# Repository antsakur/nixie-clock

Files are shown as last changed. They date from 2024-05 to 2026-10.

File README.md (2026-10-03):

# Nixie clock

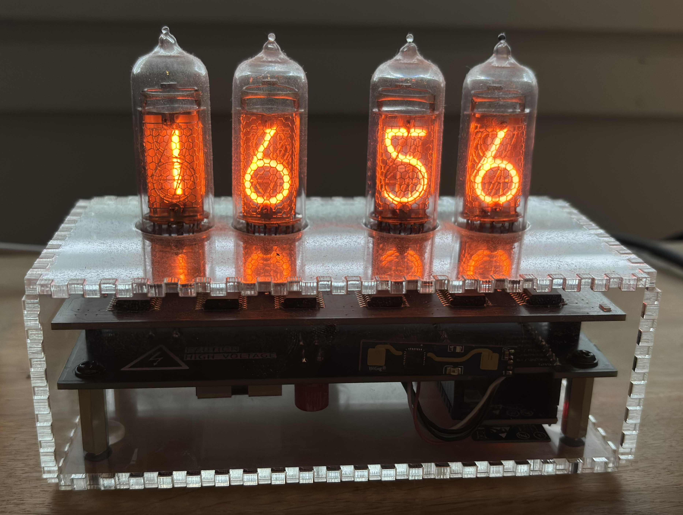
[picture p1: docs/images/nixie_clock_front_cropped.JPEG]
Nixie clock


ESP-IDF firmware for a four-tube HH:MM nixie clock on an ESP32-C6. The clock gets the time from SNTP over Wi-Fi, drives the tubes through shift registers, and serves a web page for setup and settings.

## Contents

- [What it does](#what-it-does)
- [How to use it](#how-to-use-it)
  - [First start](#first-start)
  - [Configuration](#configuration)
- [Functionality](#functionality)
  - [Display](#display)
    - [Clock](#clock)
    - [Cathode poisoning prevention routine](#cathode-poisoning-prevention-routine)
    - [Random digits](#random-digits)
  - [Brightness](#brightness)
  - [Presence](#presence)
  - [Time](#time)
  - [Network](#network)
- [How the hardware works](#how-the-hardware-works)
  - [Tubes](#tubes)
  - [Shift registers](#shift-registers)
  - [High-voltage supply](#high-voltage-supply)
  - [Presence sensor](#presence-sensor)
- [Build and flash](#build-and-flash)
- [Supported hardware](#supported-hardware)

## What it does

- Shows hours and minutes on four nixie tubes.
- Joins your saved Wi-Fi network and sets the clock from SNTP.
- Opens a setup network when it has no saved network, or when it cannot join.
- Can dim the tubes during night hours, and can turn the high-voltage supply off when nobody is nearby.
- Rolls the digits on a timer to reduce cathode poisoning.
- Crossfades digit changes when that effect is enabled.

Wi-Fi credentials are entered in the browser and stored on the clock.

## How to use it

### First start

1. Power the board from a 5 V supply that can provide 2 A, for example a USB phone charger. A 1 A supply may be insufficient. It opens a setup network named `NixieClock-XXXX`.
2. Join that network and open `http://nixie.local/`. If the name does not resolve, open `http://192.168.4.1/`.
3. Enter your SSID and password, then press **Join**. Tick **Hidden network** if the network is not advertised.
4. To access the configuration page, disconnect from the `NixieClock-XXXX` network, reconnect to your network, and open `http://nixie.local/` again.

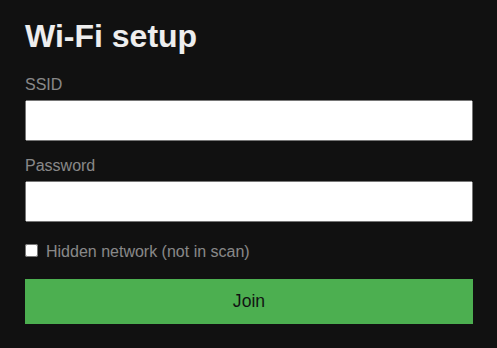
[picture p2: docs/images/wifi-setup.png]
Wi-Fi setup page


### Configuration

On your network, `http://nixie.local/` opens five menus. Each **Save settings** button stores that menu on the clock, and the values stay after a reboot.

| Menu | What you can change |
|---|---|
| Display | Fade, cathode-poisoning routine, and random digits |
| Brightness | Day and night levels, night hours, and the transition between them |
| Presence | Idle timeout that turns the tubes off |
| Time | Timezone and daylight saving |
| Network | Connection details, and forgetting the saved network |

**Forget current network** on the Network page clears the saved credentials and returns the clock to the setup network.

## Functionality

The pictures are the pages from a configured clock. The values in them are that clock's saved settings, not the defaults described here.

### Display

#### Clock

The clock normally shows the current time. When fade is enabled, a digit change crossfades from the old digits to the new ones. Fade duration is how long that crossfade takes. The default is 500 ms, and it can be set from 1 ms to 5000 ms. **Test fade** fades every digit back and forth using the fade duration that is currently set. **Show clock** returns to the time.

<figure class="clip">
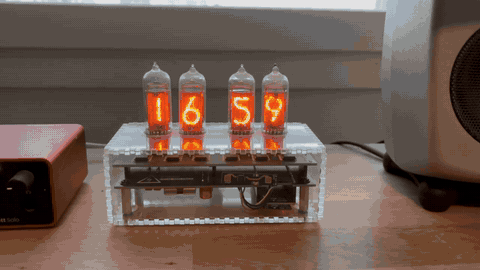
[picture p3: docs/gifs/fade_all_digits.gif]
Every digit fading

<figcaption><strong>All digits fading.</strong> Each tube crossfades to another digit and back, using the current fade duration.</figcaption>
</figure>

#### Cathode poisoning prevention routine

A nixie tube lights one cathode, the shaped digit, inside a gas-filled envelope. Metal slowly leaves the lit cathode and can settle on cathodes that stay dark. A clock repeats the same digits for long stretches, so unused digits grow dim, patchy, or fail to light. The routine walks every symbol on each tube so every cathode is lit regularly and that deposit does not build up.

You set the hold time for each digit, the starting offset, the run length, and whether it counts down. **Repeat every** is how many minutes pass between automatic runs. The default is 5 minutes. **Run cathode poisoning prevention routine** starts one run immediately.

<figure class="clip">
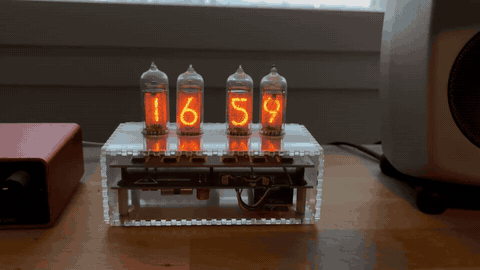
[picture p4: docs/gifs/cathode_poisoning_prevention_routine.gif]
Cathode poisoning prevention routine

<figcaption><strong>Cathode poisoning prevention.</strong> The tubes walk through every symbol so each cathode is lit.</figcaption>
</figure>

#### Random digits

Random digits shows a changing pattern instead of the time. You set the hold time and how long the pattern runs. **Run random** starts it.

<figure class="clip">
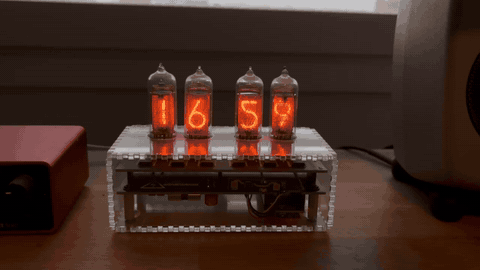
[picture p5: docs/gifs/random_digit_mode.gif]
Random digits

<figcaption><strong>Random digits.</strong> The tubes show a changing pattern instead of the time.</figcaption>
</figure>

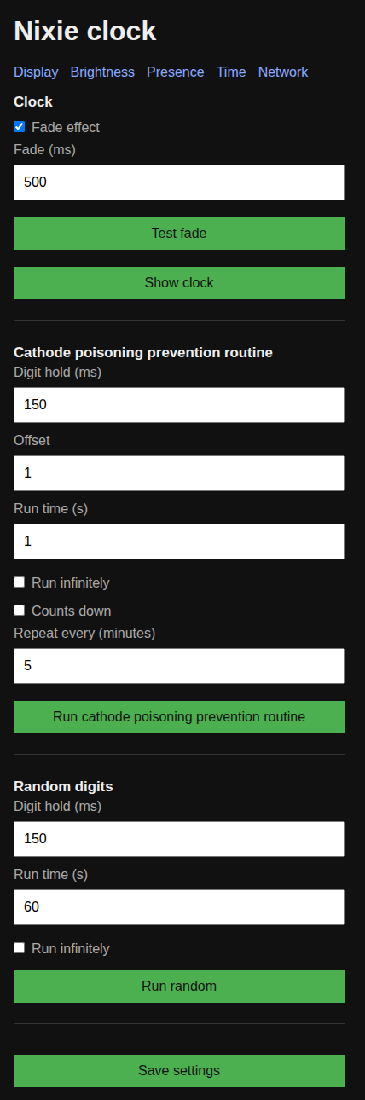
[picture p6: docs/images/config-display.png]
Display configuration page


### Brightness

Tube brightness is controlled with PWM. The brightness number is the PWM duty-cycle, from 0 to 100. The defaults are 80 during the day and 60 at night. Night mode is off by default. When it is on, it runs from a start hour until an end hour and may cross midnight. The default night hours are 23:00 to 07:00. **Transition** is how many seconds the brightness takes to move between those levels, from 1 to 60. The default is 10 seconds. **Test transition** runs one change between the day and night levels.

A brightness of 0 turns the high-voltage supply off.

<figure class="clip">
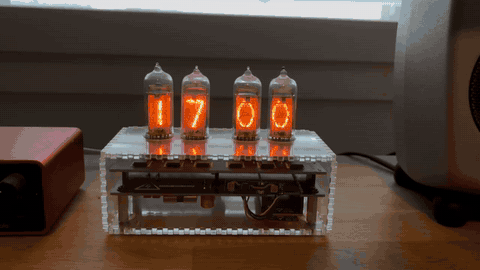
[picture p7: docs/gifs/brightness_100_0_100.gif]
Brightness moving from 100 to 0 and back to 100

<figcaption><strong>Brightness from full to off.</strong> The tubes dim from duty-cycle 100 to 0, then return to 100.</figcaption>
</figure>

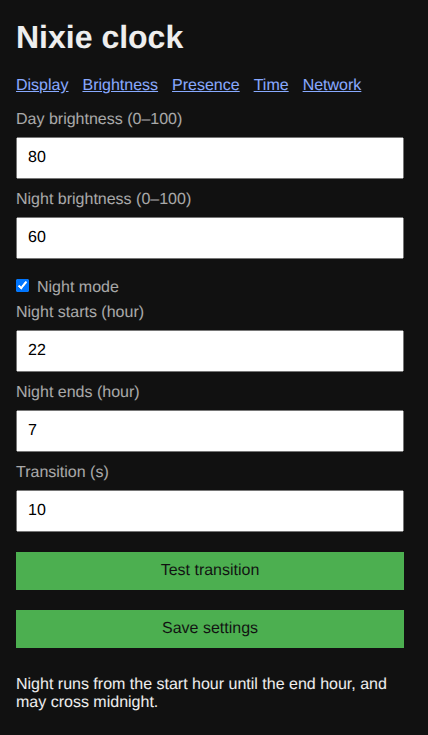
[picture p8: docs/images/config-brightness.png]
Brightness configuration page


### Presence

With the presence sensor enabled, the tubes turn off after the set number of minutes with nobody nearby. The default is 10 minutes. The allowed range is 1 to 240 minutes. Turning the sensor off leaves the tubes on, aside from a zero brightness setting.

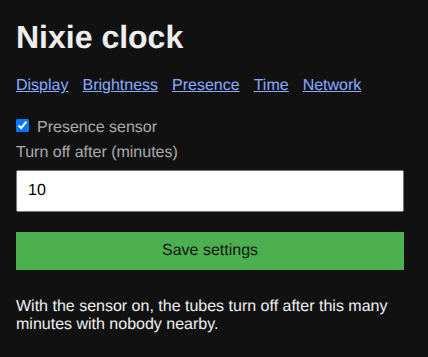
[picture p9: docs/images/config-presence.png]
Presence configuration page


### Time

Choose a timezone from the built-in list. Zones that observe daylight saving have a **Daylight saving** checkbox. The page shows the current clock time and the two SNTP servers compiled into the firmware. The defaults are `pool.ntp.org` and `time.google.com`.

The list covers UTC, the United Kingdom, Central and Eastern Europe, Finland, Moscow, India, China, Japan, Australia Eastern, and the four continental US zones.

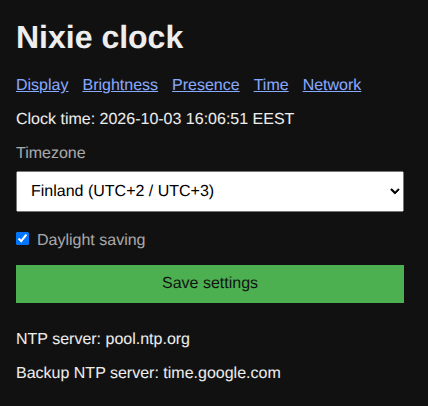
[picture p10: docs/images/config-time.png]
Time configuration page


### Network

The Network page shows the connected network, assigned IP address, firmware version, MAC address, and uptime. **Forget current network** erases the saved Wi-Fi credentials and starts the setup network again.

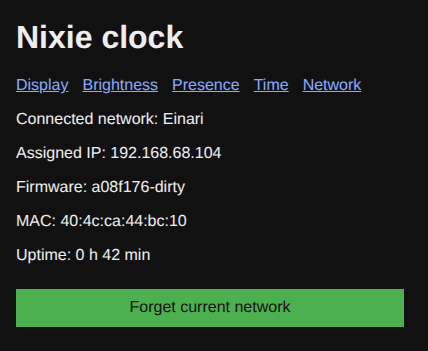
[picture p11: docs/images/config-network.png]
Network configuration page


## How the hardware works

The clock is two boards. The lower board makes 170 V from the 5 V input and carries the presence sensor. The upper board holds four IN-14 nixie tubes and the shift registers that select their digits. An ESP32-C6 development kit is the controller. It gets the time over Wi-Fi and drives the shift registers, the tube brightness, and the high-voltage enable pin.

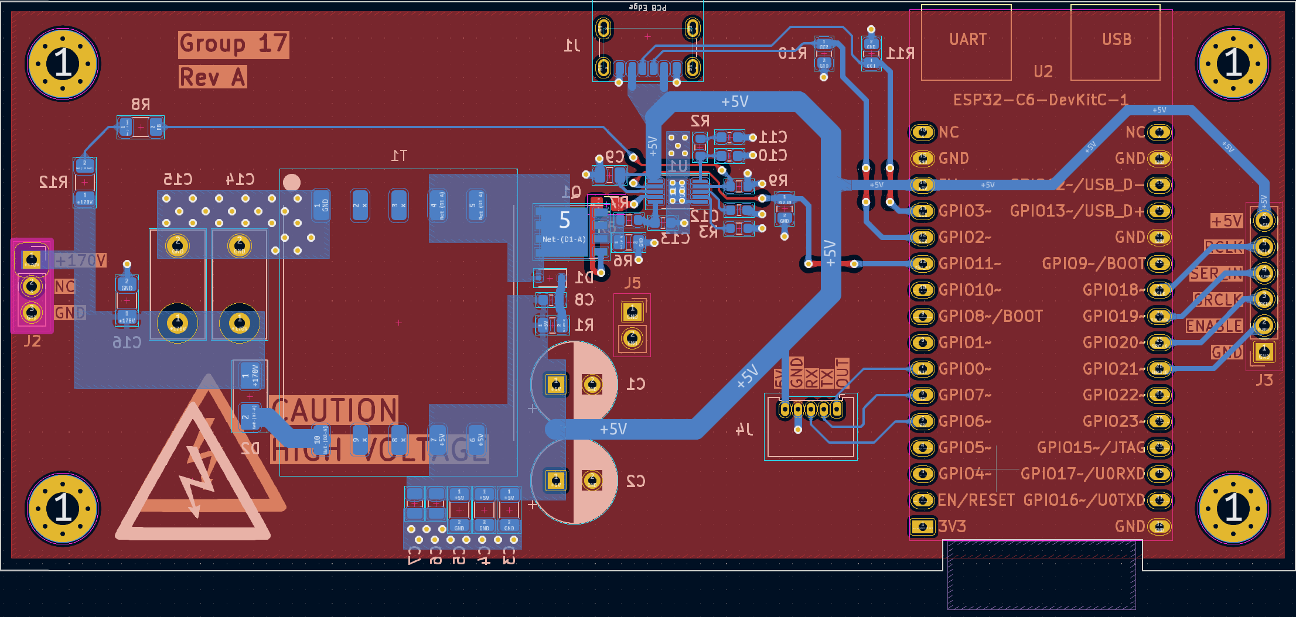
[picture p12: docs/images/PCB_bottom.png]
Lower board: 170 V supply, presence sensor, and controller


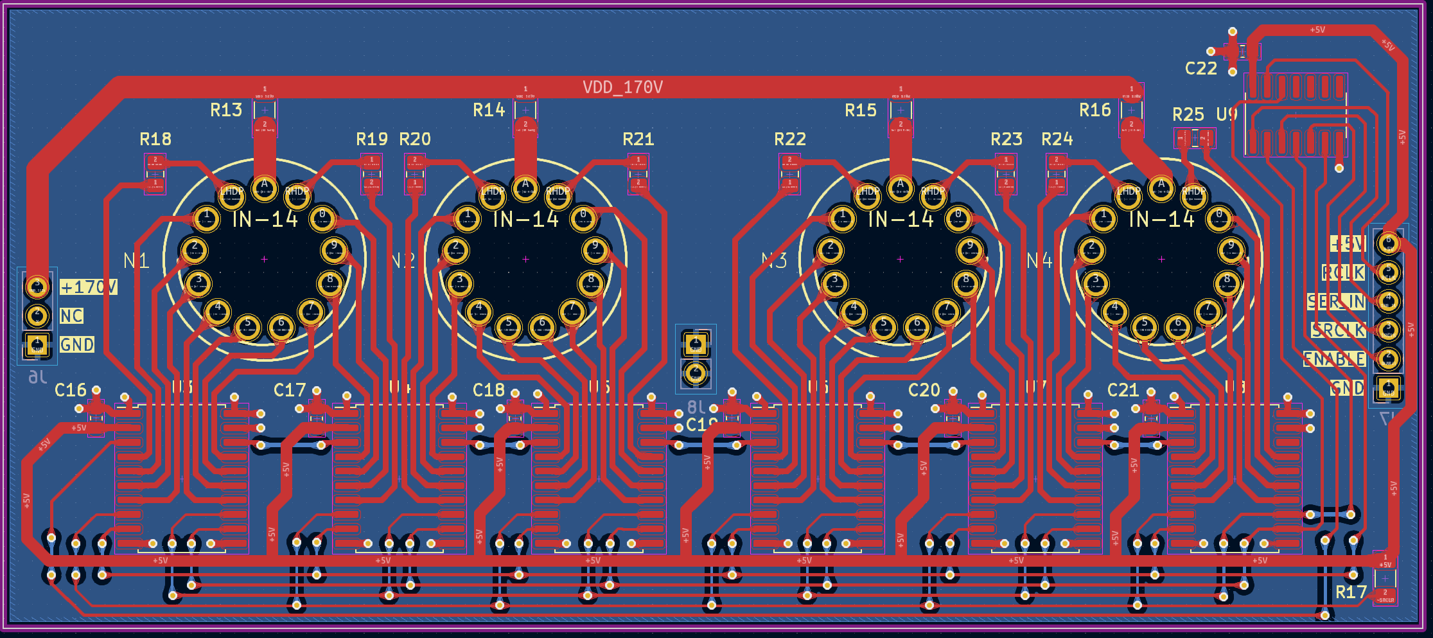
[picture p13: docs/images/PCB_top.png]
Upper board: four IN-14 tubes and shift registers


The high-voltage wiring can sit at 170 V while the clock is on. Do not touch that circuitry while it is powered.

### Tubes

Each IN-14 is a gas-filled tube with one common anode and a separate cathode for every symbol. About 170 V between the anode and a cathode ionizes the gas, and the glow takes the shape of that cathode. After the tube has struck, it keeps glowing at a lower voltage, about 145 V. The tube then looks like a short circuit, so each anode has a 13 kΩ resistor that holds the digit current to a few milliamps.

Each tube has cathodes for digits 0–9 and for a left and a right decimal point.

### Shift registers

Six TPIC6B595 shift registers are chained together. Each one has eight open-drain outputs that can pull a cathode to ground. An output that is on lights that cathode. An output that is off leaves it dark. The chain is 48 bits, sent least significant bit first:

| Bits | Tube |
|---|---|
| 47–36 | Hour tens |
| 35–24 | Hour ones |
| 23–12 | Minute tens |
| 11–0 | Minute ones |

Each group of 12 bits is one tube, in this order: left dot, digits 1 through 9, digit 0, right dot.

The controller sends serial data and a clock, then pulses the latch so all six registers update together. Output enable is a PWM signal. Its duty-cycle is the brightness number on the configuration page. The shift registers run from 5 V. Their outputs are clamped so they can sit at the tube voltage when a cathode is off.

### High-voltage supply

A flyback converter raises 5 V to 170 V for the tube anodes. An LT3757 controls the switch. The transformer is a Würth 750032051, with a 1:10 turns ratio so the switch duty-cycle stays in a practical range at 200 kHz. A BSC059N04LS6 MOSFET switches the primary. A VS-3EMH06 diode rectifies the secondary. An RCD snubber clamps the voltage spike on the MOSFET when it turns off. The converter is designed for about 20 mA at 170 V, which is enough for the four tubes. One GPIO enables the converter. Turning that pin off removes the anode voltage and the tubes go dark.

### Presence sensor

An HLK-LD2420 24 GHz radar module watches for a person nearby. It was chosen instead of a passive infrared sensor because it still sees someone who is sitting still. The clock only uses the module's presence output. A high level means someone is nearby, and a low level means the area is empty. When that output stays empty for the configured number of minutes, the firmware turns the high-voltage supply off.

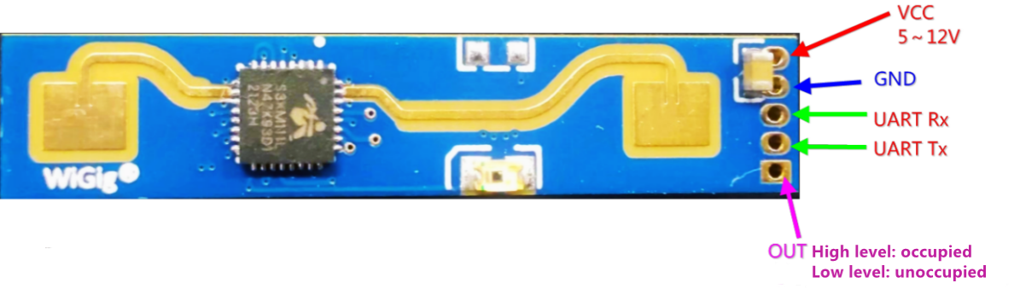
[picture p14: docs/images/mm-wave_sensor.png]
24 GHz presence sensor


## Build and flash

You need ESP-IDF 6.x. The target is `esp32c6`.

```bash
idf.py set-target esp32c6
idf.py menuconfig   # User Configuration: board and SNTP servers
idf.py build
idf.py -p /dev/ttyUSB0 flash monitor
```

In **User Configuration**:

- **Board** selects the DevKit pin map. The default is `ESP32_C6_WROOM_1`.
- **SNTP server** and **Backup SNTP server** are the only time servers the clock uses.
- **Initial connection retry count** is how many station disconnects to tolerate before giving up on credentials that have not yet received an IP, and before bringing the setup network back after a later disconnect. The default is 5.

Flash through the USB-UART bridge. The commands above use `/dev/ttyUSB0`.

## Supported hardware

| Board | Module | menuconfig |
|---|---|---|
| ESP32-C6-DevKitC-1 | ESP32-C6-WROOM-1 | `ESP32_C6_WROOM_1` (default) |
| ESP32-C6-DevKitM-1 | ESP32-C6-MINI-1 | `ESP32_C6_MINI_1` |

The firmware also expects:

- Four nixie tubes driven by shift registers (latch, data, and clock).
- A high-voltage supply with an enable pin.
- A PWM output-enable line for tube brightness.
- A presence sensor input.

Choosing the wrong board in menuconfig drives the high-voltage enable and the shift-register pins on the wrong GPIOs. The pin map for both kits is in [docs/esp32-c6-devkits.md](docs/esp32-c6-devkits.md).

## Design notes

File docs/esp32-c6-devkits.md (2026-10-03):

# ESP32-C6 DevKitM-1 vs DevKitC-1

Espressif entry-level boards for the same SoC family. They differ by **module**, **flash**, **footprint**, and **header pinout**, not by radio or CPU architecture.

Official user guides:

- [ESP32-C6-DevKitM-1](https://docs.espressif.com/projects/esp-dev-kits/en/latest/esp32c6/esp32-c6-devkitm-1/user_guide.html)
- [ESP32-C6-DevKitC-1](https://docs.espressif.com/projects/esp-dev-kits/en/latest/esp32c6/esp32-c6-devkitc-1/user_guide.html)

In this firmware, map kits in menuconfig **User Configuration → Board**:

| DevKit | Kconfig |
|---|---|
| ESP32-C6-DevKitC-1 | `ESP32_C6_WROOM_1` |
| ESP32-C6-DevKitM-1 | `ESP32_C6_MINI_1` |

Wrong board setting uses the wrong GPIOs (UART, HV PSU, shift registers). See `src/defines.h`.

---

## Differences

| | **ESP32-C6-DevKitM-1** | **ESP32-C6-DevKitC-1** |
|---|---|---|
| Module | ESP32-C6-**MINI-1**(U) | ESP32-C6-**WROOM-1**(U) |
| Typical flash (as kit docs) | **4 MB** in the chip package (`ESP32-C6FH4`) | **8 MB** SPI flash on the module |
| Module size | Smaller MINI (~13.2 × 16.6 mm class) | Larger WROOM (~18 × 25.5 mm class) |
| Antenna | PCB (`-1`) or U.FL (`-1U`) | Same: PCB vs U.FL |
| Header layout | Mini-oriented (e.g. **GPIO14** brought out; not the same J1 map as C) | Classic DevKitC (**GPIO10**, **GPIO11** on J1; extra NC pins) |
| Name | **M** = MINI module | **C** = WROOM / DevKitC-style |

The **U** SKUs change antenna only (connector vs PCB).

---

## Shared specifications

Both kits:

| Item | Spec |
|---|---|
| SoC | ESP32-C6, 32-bit RISC-V HP core (up to **160 MHz**) + LP core |
| Wi-Fi | 2.4 GHz **Wi-Fi 6** (802.11ax) |
| Bluetooth | **Bluetooth 5 (LE)** |
| 802.15.4 | Zigbee 3.0 / Thread 1.3 |
| USB | Two Type-C ports: native **USB Serial/JTAG** (USB 2.0 full speed, 12 Mbps) and **USB-UART bridge** (up to ~3 Mbps) |
| Power | USB and/or 5 V / 3.3 V headers; 5 V → 3.3 V LDO |
| Debug | BOOT, RST, RGB LED (typically **GPIO8**), current-measure jumper **J5** |
| I/O | Most GPIOs on headers (ADC, UART, I2C, SPI, USB D+/D− on GPIO13 / GPIO12) |

---

## Kit details

### ESP32-C6-DevKitM-1

- Module: ESP32-C6-MINI-1 or MINI-1U
- Flash: **4 MB** in-package on the kit Espressif documents (some MINI part numbers exist with more flash)
- Chip: **ESP32-C6FH4**
- Use when matching a small MINI production module

### ESP32-C6-DevKitC-1 (user guide v1.2)

- Module: ESP32-C6-WROOM-1 or WROOM-1U
- Flash: **8 MB** SPI
- Chip: ESP32-C6 with flash on the module
- Use when you want extra flash and the usual DevKitC header map

---

## Firmware pin map (this project)

| Signal | WROOM-1 / DevKitC-1 | MINI-1 / DevKitM-1 |
|---|---|---|
| Presence | GPIO0 | GPIO0 |
| USB-C CC1 / CC2 | GPIO2 / GPIO1 | — |
| UART RX / TX | GPIO6 / GPIO7 | GPIO4 / GPIO5 |
| HV PSU enable | GPIO11 | GPIO7 |
| Shift-reg latch | GPIO18 | GPIO15 |
| Shift-reg data | GPIO19 | GPIO18 |
| Shift-reg clock | GPIO20 | GPIO19 |
| Shift-reg output enable (PWM) | GPIO21 | GPIO20 |

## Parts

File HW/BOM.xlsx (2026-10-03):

Item # | Qty |  | Ref Des | Manufacturer | Manf part num | Description | Footprint | Type | Digikey price/pc (€) | Total
 |  | Comment
 |  | Capacitors |  |  |  |  |  |  | excluding VAT
 | 1 | 100pF | C10 | Yageo | CC0603JRNPO9BN101 | Multilayer Ceramic Capacitor, 100 pF, 50 V, ± 5%, C0G (NP0), 0603 [1608 Metric] | 0603 | SMT | 0.09 | 0.09
 | 1 | 10nf, 500V, X7R | C16 | Wurth Elektronik | 885342208009 | Cap Cer 10000PF 500V X7R 1206 | 1206 | SMT | 0.12 | 0.12
 | 1 | 10nf | C13 | Murata | GCM188R72A103KA37D | Multilayer Ceramic Capacitor, 0.01 uF, 100 V, ± 10%, X7R, 0603 [1608 Metric] | 0603 | SMT | 0.09 | 0.09
 | 2 | 22nf, 100V | C8,C11 | Murata | GCM188R72A223KA37J | Multilayer Ceramic Capacitor, 0.022 uF, 100 V, ± 10%, X7R, 0603 [1608 Metric] | 0603 | SMT | 0.1 | 0.20
 | 2 | 68nf, 400V | C14, C15 | Wurth Elektronik | 890283422001CS | Cap, 0.068Uf, 400V, Film, Radial Rohs Compliant: Yes |Wurth Elektronik 890283422001CS | WCAP-FTBE_L10.5xH11xP7.5 | THT | 0.44 | 0.88
 | 7 | 100nf, 16V | C12, C17-22 | Yageo | CC0603KRX7R7BB104 | Multilayer Ceramic Capacitor, 0.1 uF, 16 V, ± 10%, X7R, 0603 [1608 Metric] | 0603 | SMT | 0.039 | 0.27
 | 2 | 1uf, 25V, X7R | C6,C7 | Samsung | CL21B105KAFNNNE | Multilayer Ceramic Capacitor, 1 uF, 25 V, ± 10%, X7R, 0805 [2012 Metric] | 0805 | SMT | 0.09 | 0.18
 | 3 | 10uf, 25V, X7R | C3,C4,C5 | Samsung | CL31B106KAHNFNE | Multilayer Ceramic Capacitor, 10 uF, 25 V, ± 10%, X7R, 1206 [3216 Metric] | 1206 | SMT | 0.21 | 0.63
 | 1 | 47uF, 16V, X7R | C9 | Murata | GRM21BR71C475KE51L | Multilayer Ceramic Capacitor, 4.7 uF, 16 V, ± 10%, X7R, 0805 [2012 Metric] | 0805 | SMT | 0.14 | 0.14
 | 2 | 47uF, 25V | C1,C2 | Wurth Elektronik | 870025574002 | WCAP-PTG5 Aluminum Polymer Capacitors | WCAP-PTG5_D8xH8xP3.5 | THT | 0.68 | 1.36
 | 1 | 0 | R5 | Yageo | RC0805FR-070RL | Thick film chip resistor; smd; 0805; 0.00R; 0.125W; 1%; ; operating temperature: -55°C~125°C | 0805 | SMT | 0.09 | 0.09
 | 1 | 2 | R5 | Yageo | RC0805FR-072RL | SMD Chip Resistor, 2 Ohm, ± 1%, 125 mW, 0805 [2012 Metric], Thick Film, General Purpose | 0805 | SMT | 0.09 | 0.09
 | 1 | 33m, 3/4W | R6 | Thin Film Tech | D1WEL0805MR033F-T5 | Res 0.033 Ohm 1% 3/4W 0805 | 0805 | SMT | 0.42 | 0.42
 | 1 | 20 | R12 | Yageo | RC1206JR-0720RL | SMD Chip Resistor, 20 Ohm, ± 5%, 250 mW, 1206 [3216 Metric], Thick Film, General Purpose | 1206 | SMT | 0.09 | 0.09
 | 1 | 22 | R7 | Yageo | RC0603FR0722RL | SMD Chip Resistor, 22 Ohm, ± 1%, 100 mW, 0603 [1608 Metric], Thick Film, General Purpose | 0603 | SMT | 0.09 | 0.09
 | 1 | 4.7k, 0.4W | R1 | Vishay | RCS08054K70FKEA | Res Thick Film 0805 4.7K Ohm 1% 0.4W ±100ppm/°C Pad SMD Automotive Medical T/R | 0805 | SMT | 0.12 | 0.12
 | 2 | 5.1k, 1% | R10,R11 | Yageo | RC0805FR-075K1L | SMD Chip Resistor, 5.1 kOhm, ± 1%, 125 mW, 0805 [2012 Metric], Thick Film, General Purpose | 0805 | SMT | 0.09 | 0.18
 | 1 | 6.8k | R2 | Yageo | RC0603FR-076K8L | SMD Chip Resistor, 6.8 kOhm, ± 1%, 100 mW, 0603 [1608 Metric], Thick Film, General Purpose | 0603 | SMT | 0.09 | 0.09
 | 5 | 13k | R13-17 | KOA Speer | RK73B2BTTD133J | Res Thick Film 1206 13K Ohm 5% 0.25W(1/4W) ±200ppm/C Pad SMD Automotive T/R | 1206 | SMT | 0.03 | 0.15
 | 1 | 15k | R9 | Yageo | RC0603FR-0715KL | SMD Chip Resistor, 15 kOhm, ± 1%, 100 mW, 0603 [1608 Metric], Thick Film, General Purpose | 0603 | SMT | 0.09 | 0.09
 | 1 | 63.4k | R3 | Stackpole Electronics | RMCF0603FT63K4 | Res Thick Film 0603 63.4K Ohm 1% 1/10W ±100ppm/°C Molded SMD SMD Paper T/R | 0603 | SMT | 0.09 | 0.09
 | 8 | 100k | R18-R25 | Yageo | RC0805FR-07100KL |  | 0805 | SMT
 | 1 | 1.6M | R8 | Yageo | RC1206FR-071M6L | SMD Chip Resistor, 1.6 MOhm, ± 1%, 250 mW, 1206 [3216 Metric], Thick Film, General Purpose | 1206 | SMT | 0.09 | 0.09
 | 1 | 2A, 600V | D2 | Vishay | VS-3EMH06-M3/5AT | Diode Hyper Fast Recovery Rectifier 600V 3A 2-Pin DO-214AC Plastic T/R | SMA (DO-214AC) | SMT | 0.40 | 0.40
 | 1 | 0.25A, 100V | D1 | Diodes Inc. | 1N4148WSF-7 | Rectifier Diode Small Signal Switching 100V 0.25A 4ns 2-Pin SOD-323F T/R | SOD323F | SMT | 0.17 | 0.17
 | 1 | 40V | Q1 | Infineon | BSC059N04LS6 | OptiMO 6 40V power MOSFETs combining best-in-class RDS(on) with superior switching performance | TDSON-8 FL | SMT | 1.05 | 1.05
 | 1 | 10uH | T1 | Wurth Elektronik | 750032051 | Pulse Transformer, 1: 10, 10 H, 0.7 Ohm, 1 Kv | - | SMT | 4.68 | 4.68
 | 1 | LT3757A | U1 | Analog Devices | LT3757AEMSE#PBF | DC DC Cntrlr Single-OUT Flyback Controller 2.9V to 40V Input Automotive 10-Pin MSOP EP | 10-TFSOP, 10-MSOP (0.118", 3.00mm Width) Exposed Pad | SMT | 6.15 | 6.15
 | 6 | TPIC6B595 | U3-U8 | Texas Instruments | TPIC6B595DWR | 8 Bit Sipo Shift Register, SOIC-20; Shif; Msl: Msl 1 - Unlimited; Svhc: No Svhc (15-JAN-2019) | 20-SOIC | SMT | 1.39 | 8.34
 | 1 | SN74HCT04 | U9 | Texas Instruments | SN74HCT04DR | 6-ch, 4.5-V to 5.5-V inverters with TTL-compatible CMOS inputs 14-SOIC -40 to 85 | 14-SOIC | SMT | 0.33 | 0.33
 | 1 | USB4125 | J1 | GCT | USB4125-GF-A-0190 | 24 (6+18 Dummy) Position USB-C (USB TYPE-C) USB 2.0 Receptacle Connector | USB 6P | THT | 0.62 | 0.62
 | 1 | 5POS 1.25mm | J4 | Molex | 0530480510 | Conn Shrouded Header (4 Sides) HDR 5 POS 1.25mm Solder RA Side Entry Thru-Hole PicoBlade Tray | 1x05_P1.25mm | THT | 0.45 | 0.45
 | 1 | 5POS 1.25mm | - | Molex | 0510210500 | MOLEX 51021-0500 1.25mm Pitch Housing Female 5p PicoBlade Wire-to-Wire +Wire-to-Board | - | CONNECTOR | 0.24 | 0.24
 | 10 | 28-32AWG | - | Molex | 0500588000 | 1.25mm Pitch, PicoBlade Female Crimp Terminal, Tin (Sn) Plating, 28-32 AWG, Reel | - | CONNECTOR | 0.04 | 0.39
 | 1 | 2POS socket | J5 | Sullins | PPPC021LFBN-RC | Female, 2 C, Straight .100" CC; 3.20mm Tail, No Mounting; PBT, Phos. Bronze, 105 C | 1x02_P2.54mm | THT | 0.31 | 0.31
 | 1 | 3POS socket | J2 | Sullins | PPPC031LFBN-RC | 3 Position Total Single Row 2.54 mm Pitch Straight Female Header | 1x03_P2.54mm | THT | 0.35 | 0.35
 | 1 | 6POS socket | J3 | Sullins | PPPC061LFBN-RC | 6 Position Header Connector 0.100 (2.54mm) Through Hole Gold" | 1x06_P2.54mm | THT | 0.50 | 0.50
 | 1 | 2POS header | J8 | Sullins | PREC002SAAN-RC | Automotive Connectors CLIP HSG FOR 090 II MLC | 1x02_P2.54mm | THT | 0.09 | 0.09
 | 1 | 3POS header | J6 | Sullins | PREC003SAAN-RC | Conn Header Vert 3POS 2.54MM | 1x03_P2.54mm | THT | 0.09 | 0.09
 | 1 | 6POS header | J7 | Sullins | PREC006SAAN-RC | Conn Header .100" Sngl Str 6POS | 1x06_P2.54mm | THT | 0.14 | 0.14
 | 60 | Tube socket |  | Preci-Dip | 01401-87-3010 | Pin Receptacle Connector 0.014" |  | THT | 0.0873 | 5.24
 | 1 | ESP32-C6 | U2 | Espressif | ESP32-C6-DEVKITC-1-N8 | Development Board WiFi, Bluetooth® 5, Flash 8MB | 2x15_P2.54mm | THT | 8.31 | 8.31
 | 2 | 15POS socket |  | Sullins | PPTC151LFBN-RC | Board Connector, 15 Contact(s), 1 Row(s), Female, Straight, 0.1 inch Pitch, Solder Terminal, Locking | 2x15_P2.54mm | THT | 0.91 | 1.82
 | 4 | 970150321 |  | Wurth Elektronik | 970150321 | WA-SSTII Steel Spacer Stud Metric Thread int./int. | M3x0.5 15mm |  | 0.34 | 1.36
 | 4 | 50M030050P008 |  | Essentra | 50M030050P008 | Pan Phillips Screw, M3 X .5 Thread, 8MM Lg | Essentra Components 50M030050P008 | M3x0.5 8mm |  | 0.12 | 0.48
 |  |  |  |  |  |  |  |  | Total w/o VAT | 45.22
 |  |  |  |  |  |  |  |  | TOTAL VAT 24% | 56.07404

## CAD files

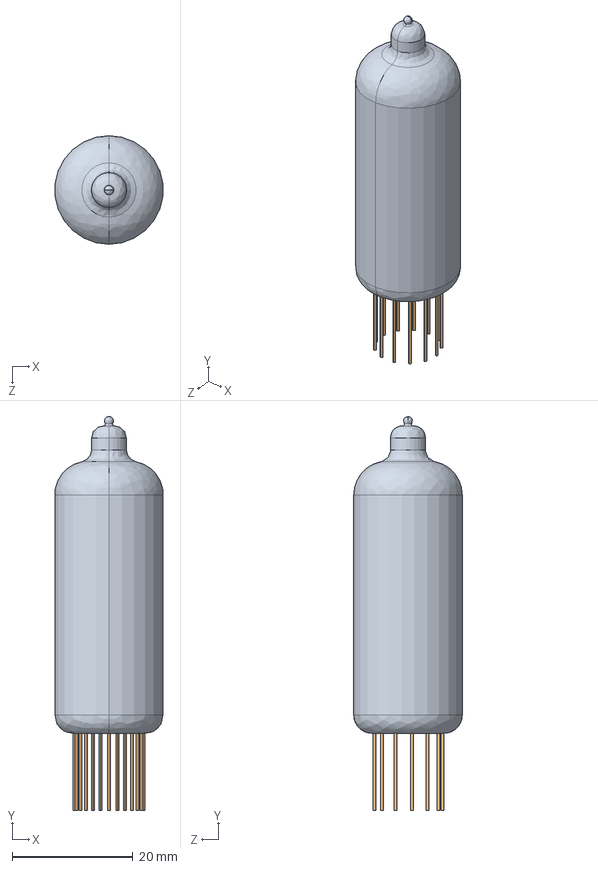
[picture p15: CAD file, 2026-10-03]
HW/KiCad/Sulari_TOP/step/NX-SZP-IN14-v01.STEP
17.9 x 65.3 x 18.0 mm
NX-SZP-IN14-10-v01_1
NX-SZP-IN14-11-v01_1 x 13
NX-SZP-IN14-12-v01_1
NX-SZP-IN14-13-v01_1
NX-SZP-IN14-14-v01_1
NX-SZP-IN14-15-v01_1
NX-SZP-IN14-16-v01_1
NX-SZP-IN14-17-v01_1
NX-SZP-IN14-18-v01_1 x 2
NX-SZP-IN14-00-v01_1
NX-SZP-IN14-01-v01_1
NX-SZP-IN14-02-v01_1
NX-SZP-IN14-03-v01_1
NX-SZP-IN14-04-v01_1
NX-SZP-IN14-05-v01_1
NX-SZP-IN14-06-v01_1
NX-SZP-IN14-07-v01_1
NX-SZP-IN14-08-v01_1
NX-SZP-IN14-09-v01_1
NX-SZP-IN14-19-v01_1
NX-SZP-IN14-20-v01_1
NX-SZP-IN14-21-v01_1
NX-SZP-IN14-21-v02_1

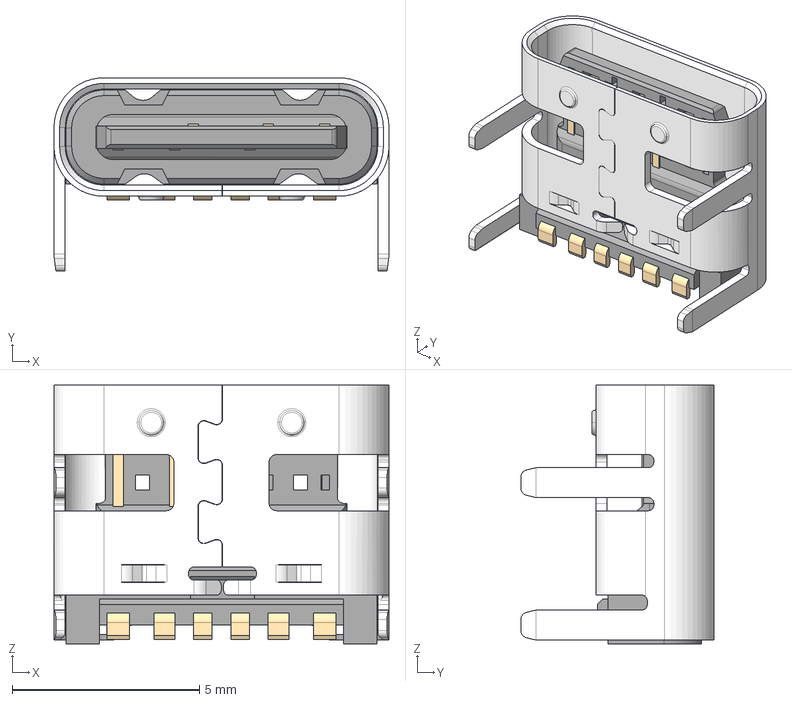
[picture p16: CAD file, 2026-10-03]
HW/KiCad/Sulari_BOTTOM/sulari_step/USB4125-GF-A-0190.stp
8.94 x 5.16 x 6.90 mm

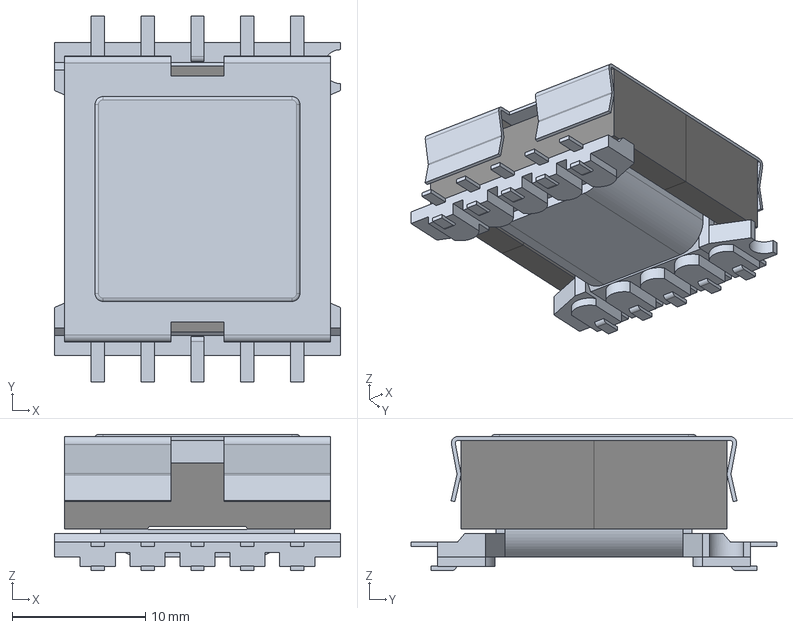
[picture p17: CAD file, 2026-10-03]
HW/KiCad/Sulari_BOTTOM/sulari_step/o54870v246 WE-FB_3751_EFD20_1 (rev1).stp
21.5 x 27.5 x 10.2 mm

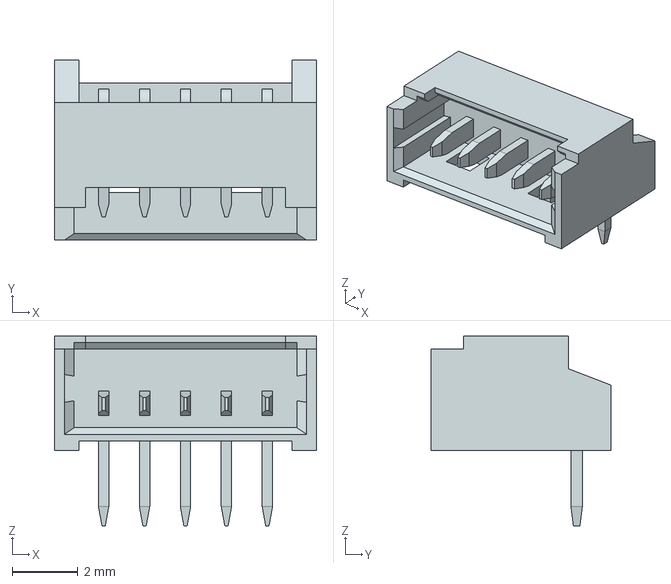
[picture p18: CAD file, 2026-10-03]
HW/KiCad/Sulari_BOTTOM/sulari_step/530480510.stp
8.00 x 5.50 x 5.80 mm

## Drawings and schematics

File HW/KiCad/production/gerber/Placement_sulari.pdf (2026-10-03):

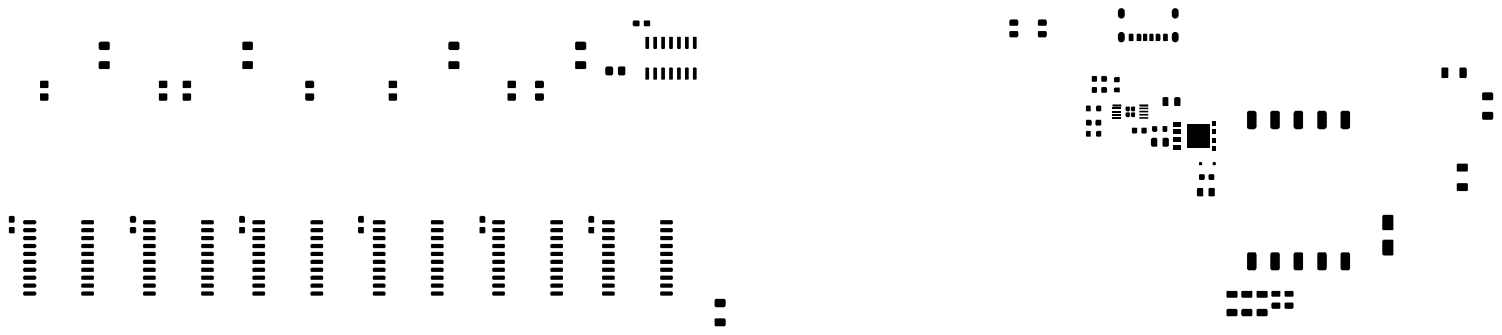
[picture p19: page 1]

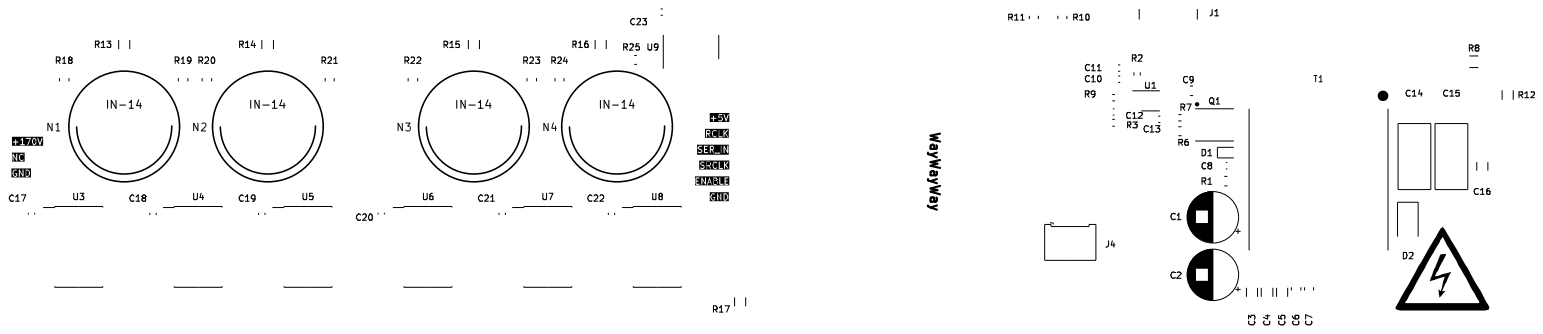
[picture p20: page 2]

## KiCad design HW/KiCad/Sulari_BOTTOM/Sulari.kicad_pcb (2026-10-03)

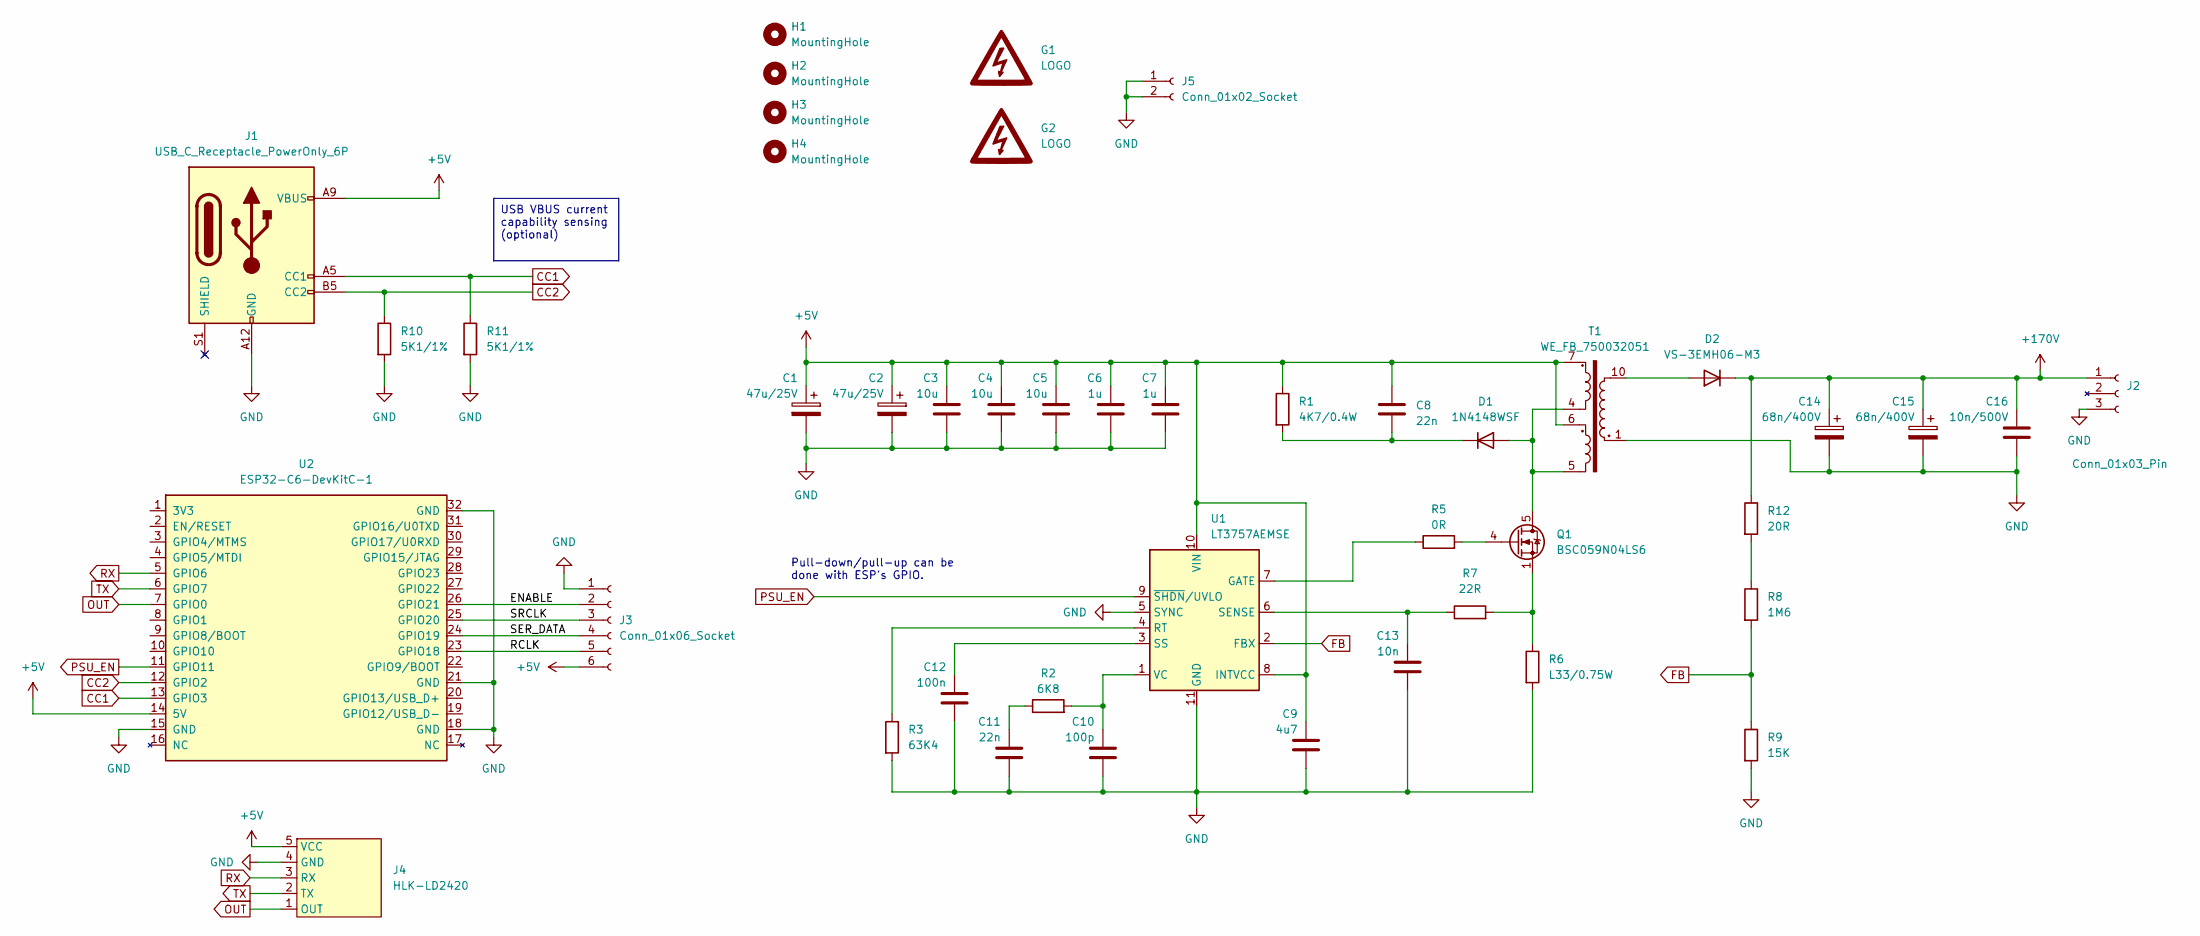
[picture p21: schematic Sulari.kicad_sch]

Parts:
C1, C2: 47u/25V; CP_Radial_D8.0mm_P3.50mm
C3, C4, C5: 10u; C_1206_3216Metric
C6, C7: 1u; C_0805_2012Metric
C8, C11: 22n; C_0603_1608Metric
C9: 4u7; C_0805_2012Metric
C10: 100p; C_0603_1608Metric
C12: 100n; C_0603_1608Metric
C13: 10n; C_0603_1608Metric
C14, C15: 68n/400V; C_Rect_L10.3mm_W5.0mm_P7.50mm_MKS4
C16: 10n/500V; C_1206_3216Metric_Pad1.33x1.80mm_HandSolder
D1: 1N4148WSF; D_SOD-323F
D2: VS-3EMH06-M3; D_SMA
G1, G2: LOGO; HIGH_VOLTAGE_LOGO
H1, H2, H3, H4: MountingHole; MountingHole_3.2mm_M3_Pad_Via
J1: USB_C_Receptacle_PowerOnly_6P; USB_C_Receptacle_GCT_USB4125-xx-x-0190_6P_TopMnt_Horizontal
J2: Conn_01x03_Pin; PinSocket_1x03_P2.54mm_Vertical
J3: Conn_01x06_Socket; PinSocket_1x06_P2.54mm_Vertical
J4: HLK-LD2420; Molex_PicoBlade_53048-0510_1x05_P1.25mm_Horizontal
J5: Conn_01x02_Socket; PinSocket_1x02_P2.54mm_Vertical
Q1: BSC059N04LS6; PG-TDSON-8-FL_correct
R1: 4K7/0.4W; R_0805_2012Metric
R2: 6K8; R_0603_1608Metric
R3: 63K4; R_0603_1608Metric
R5: 0R; R_0805_2012Metric_Pad1.20x1.40mm_HandSolder
R6: L33/0.75W; R_0805_2012Metric
R7: 22R; R_0603_1608Metric
R8: 1M6; R_1206_3216Metric
R9: 15K; R_0603_1608Metric
R10, R11: 5K1/1%; R_0805_2012Metric
R12: 20R; R_1206_3216Metric_Pad1.30x1.75mm_HandSolder
T1: WE_FB_750032051; WE_FB 750032051
U1: LT3757AEMSE; MSOP-10-1EP_3x3mm_P0.5mm_EP1.68x1.88mm_ThermalVias
U2: ESP32-C6-DevKitC-1

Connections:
+5V: C1.1, C2.1, C3.1, C4.1, C5.1, C6.1, C7.1, C8.1, C9.1, J1.A9 (VBUS), J1.B9 (VBUS), J3.6, J4.5 (VCC), R1.1, T1.6, T1.7, U1.8 (INTVCC), U1.10 (VIN), U2.14 (5V)
+170V: C14.1, C15.1, C16.1, D2.1 (K), J2.1, R12.1
/ENABLE: J3.2, U2.26 (GPIO21)
/RCLK: J3.5, U2.23 (GPIO18)
/SER_DATA: J3.4, U2.24 (GPIO19)
/SRCLK: J3.3, U2.25 (GPIO20)
CC1: J1.A5 (CC1), R11.1, U2.13 (GPIO3)
CC2: J1.B5 (CC2), R10.1, U2.12 (GPIO2)
FB: R8.2, R9.1, U1.2 (FBX)
GND: C1.2, C2.2, C3.2, C4.2, C5.2, C6.2, C7.2, C9.2, C10.2, C11.2, C12.2, C13.2, C14.2, C15.2, C16.2, J1.A12 (GND), J1.B12 (GND), J2.3, J3.1, J4.4 (GND), J5.1, J5.2, R3.2, R6.2, R9.2, R10.2, R11.2, T1.1, U1.5 (SYNC), U1.11 (GND), U2.15 (GND), U2.18 (GND), U2.21 (GND), U2.32 (GND)
unnamed: C11.1, R2.1
unnamed: D1.2 (A), Q1.5 (D), T1.4, T1.5
unnamed: C8.2, D1.1 (K), R1.2
unnamed: D2.2 (A), T1.10
unnamed: Q1.4 (G), R5.2
unnamed: Q1.1 (S), R6.1, R7.2
unnamed: R8.1, R12.2
unnamed: R5.1, U1.7 (GATE)
unnamed: R3.1, U1.4 (RT)
unnamed: C13.1, R7.1, U1.6 (SENSE)
unnamed: C12.1, U1.3 (SS)
unnamed: C10.1, R2.2, U1.1 (VC)
OUT: J4.1 (OUT), U2.7 (GPIO0)
PSU_EN: U1.9 (~SHDN/UVLO), U2.11 (GPIO11)
RX: J4.3 (RX), U2.5 (GPIO6)
TX: J4.2 (TX), U2.6 (GPIO7)

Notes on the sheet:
USB VBUS current capability sensing (optional)
Pull-down/pull-up can be done with ESP's GPIO.

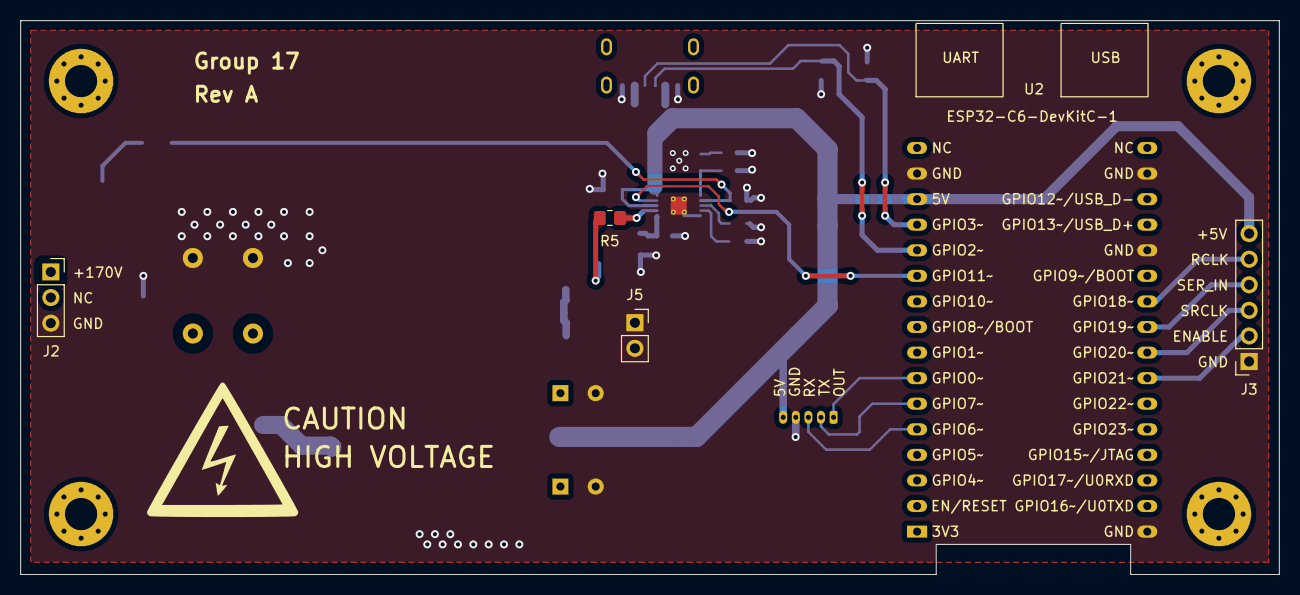
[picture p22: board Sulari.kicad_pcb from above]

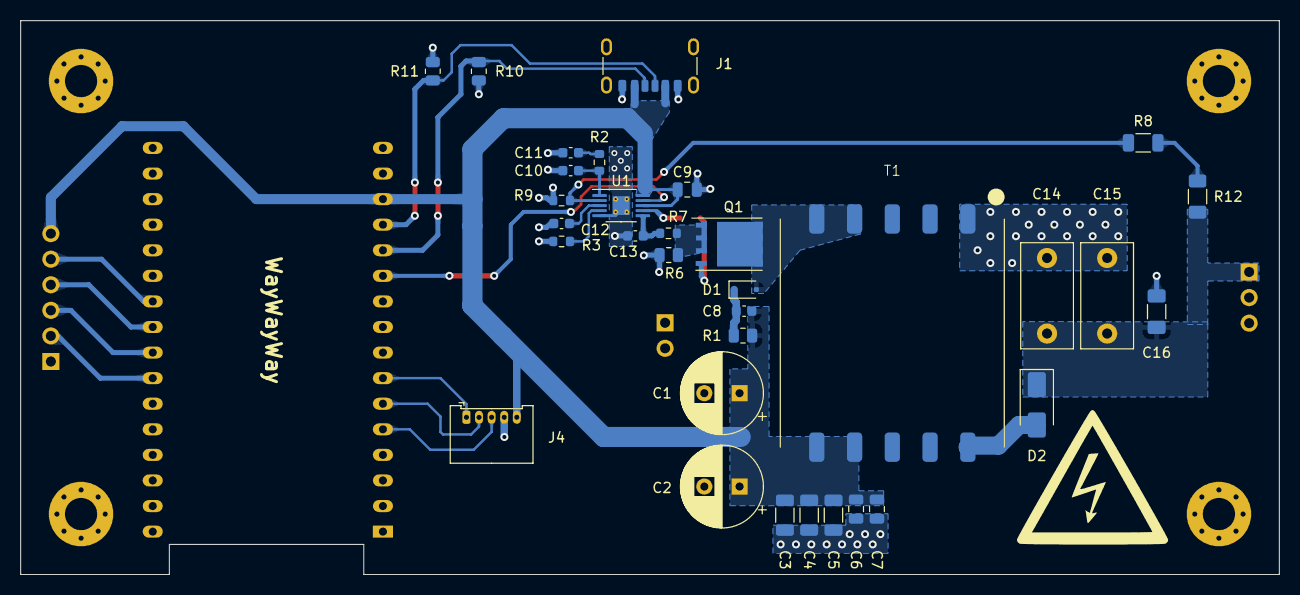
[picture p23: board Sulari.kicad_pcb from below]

Board: 2 copper layers, 125.0 x 55.0 mm, 44 parts (34 on the bottom side), 26 nets.

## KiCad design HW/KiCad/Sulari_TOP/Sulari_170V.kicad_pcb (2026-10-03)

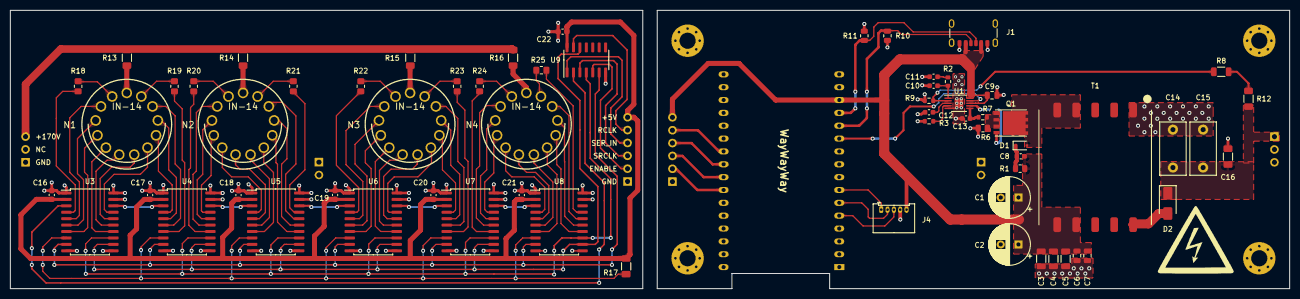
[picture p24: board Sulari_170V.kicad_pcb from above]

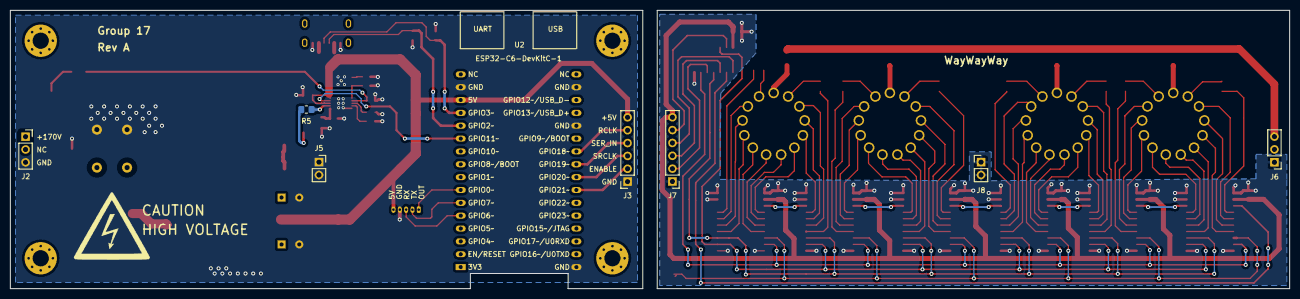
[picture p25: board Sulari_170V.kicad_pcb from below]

Board: 2 copper layers, 252.9 x 55.0 mm, 78 parts (13 on the bottom side), 101 nets.

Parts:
C1, C2: 47u/25V; CP_Radial_D8.0mm_P3.50mm
C3, C4, C5: 10u; C_1206_3216Metric
C6, C7: 1u; C_0805_2012Metric
C8, C11: 22n; C_0603_1608Metric
C9: 4u7; C_0805_2012Metric
C10: 100p; C_0603_1608Metric
C12: 100n; C_0603_1608Metric
C13: 10n; C_0603_1608Metric
C14, C15: 68n/400V; C_Rect_L10.3mm_W5.0mm_P7.50mm_MKS4
C16, C17, C18, C19, C20, C21, C22: 100n; C_0603_1608Metric_Pad1.08x0.95mm_HandSolder
C16#2: 10n/500V; C_1206_3216Metric_Pad1.33x1.80mm_HandSolder
D1: 1N4148WSF; D_SOD-323F
D2: VS-3EMH06-M3; D_SMA
G1, G2: LOGO; HIGH_VOLTAGE_LOGO
H1, H2, H3, H4: MountingHole; MountingHole_3.2mm_M3_Pad_Via
J1: USB_C_Receptacle_PowerOnly_6P; USB_C_Receptacle_GCT_USB4125-xx-x-0190_6P_TopMnt_Horizontal
J2: Conn_01x03_Pin; PinSocket_1x03_P2.54mm_Vertical
J3: Conn_01x06_Socket; PinSocket_1x06_P2.54mm_Vertical
J4: HLK-LD2420; Molex_PicoBlade_53048-0510_1x05_P1.25mm_Horizontal
J5: Conn_01x02_Socket; PinSocket_1x02_P2.54mm_Vertical
J6: Conn_01x03; PinHeader_1x03_P2.54mm_Vertical
J7: Conn_01x06; PinHeader_1x06_P2.54mm_Vertical
J8: Conn_01x02; PinHeader_1x02_P2.54mm_Vertical
N1, N2, N3, N4: IN-14; nixies-us-IN-14-socket
Q1: BSC059N04LS6; PG-TDSON-8-FL
R1: 4K7/0.4W; R_0805_2012Metric
R2: 6K8; R_0603_1608Metric
R3: 63K4; R_0603_1608Metric
R5: 0R; R_0805_2012Metric_Pad1.20x1.40mm_HandSolder
R6: L33/0.75W; R_0805_2012Metric
R7: 22R; R_0603_1608Metric
R8: 1M6; R_1206_3216Metric
R9: 15K; R_0603_1608Metric
R10, R11: 5K1/1%; R_0805_2012Metric
R12: 20R; R_1206_3216Metric_Pad1.30x1.75mm_HandSolder
R13, R14, R15, R16, R17: 13K; R_1206_3216Metric_Pad1.30x1.75mm_HandSolder
R18, R19, R20, R21, R22, R23, R24, R25: 100k; R_0805_2012Metric_Pad1.20x1.40mm_HandSolder
T1: WE_FB_750032051; WE_FB 750032051
U1: LT3757AEMSE; MSOP-10-1EP_3x3mm_P0.5mm_EP1.68x1.88mm
U2: ESP32-C6-DevKitC-1
U3, U4, U5, U6, U7, U8: TPIC6B595; SOIC-20W_7.5x12.8mm_P1.27mm
U9: SN74HCT04, 6-ch 5V logic inverter; SOIC-14_3.9x8.7mm_P1.27mm

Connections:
+5V: C1.1, C2.1, C3.1, C4.1, C5.1, C6.1, C7.1, C8.1, C9.1, C16.1, C17.1, C18.1, C19.1, C20.1, C21.1, C22.1, J1.A9 (VBUS), J1.B9 (VBUS), J3.6, J4.5 (VCC), J7.6, R1.1, R17.1, T1.6, T1.7, U1.8 (INTVCC), U1.10 (VIN), U2.14 (5V), U3.2 (VCC), U4.2 (VCC), U5.2 (VCC), U6.2 (VCC), U7.2 (VCC), U8.2 (VCC), U9.14
+170V: C14.1, C15.1, C16#2.1, D2.1 (K), J2.1, R12.1
/ENABLE: J3.2, U2.26 (GPIO21)
/RCLK: J3.5, U2.23 (GPIO18)
/SER_DATA: J3.4, U2.24 (GPIO19)
/SRCLK: J3.3, U2.25 (GPIO20)
/VDD_170V: J6.3, R13.1, R14.1, R15.1, R16.1
/~SRCLR: R17.2, U3.8 (~SRCLR), U4.8 (~SRCLR), U5.8 (~SRCLR), U6.8 (~SRCLR), U7.8 (~SRCLR), U8.8 (~SRCLR)
CC1: J1.A5 (CC1), R11.1, U2.13 (GPIO3)
CC2: J1.B5 (CC2), R10.1, U2.12 (GPIO2)
ENABLE: J7.2, U9.5
FB: R8.2, R9.1, U1.2 (FBX)
GND: C1.2, C2.2, C3.2, C4.2, C5.2, C6.2, C7.2, C9.2, C10.2, C11.2, C12.2, C13.2, C14.2, C15.2, C16.2, C16#2.2, C17.2, C18.2, C19.2, C20.2, C21.2, C22.2, J1.A12 (GND), J1.B12 (GND), J2.3, J3.1, J4.4 (GND), J5.1, J5.2, J6.1, J7.1, J8.1, J8.2, R3.2, R6.2, R9.2, R10.2, R11.2, T1.1, U1.5 (SYNC), U1.11 (GND), U2.15 (GND), U2.18 (GND), U2.21 (GND), U2.32 (GND), U3.1 (PGND), U3.10 (PGND), U3.11 (PGND), U3.19 (LGND), U3.20 (PGND), U4.1 (PGND), U4.10 (PGND), U4.11 (PGND), U4.19 (LGND), U4.20 (PGND), U5.1 (PGND), U5.10 (PGND), U5.11 (PGND), U5.19 (LGND), U5.20 (PGND), U6.1 (PGND), U6.10 (PGND), U6.11 (PGND), U6.19 (LGND), U6.20 (PGND), U7.1 (PGND), U7.10 (PGND), U7.11 (PGND), U7.19 (LGND), U7.20 (PGND), U8.1 (PGND), U8.10 (PGND), U8.11 (PGND), U8.19 (LGND), U8.20 (PGND), U9.7
unnamed: C11.1, R2.1
unnamed: D1.2 (A), Q1.5 (D), T1.4, T1.5
unnamed: C8.2, D1.1 (K), R1.2
unnamed: D2.2 (A), T1.10
unnamed: N1.A, R13.2
unnamed: N1.LHDP, R18.2
unnamed: N1.RHDP, R19.1
unnamed: N2.A, R14.2
unnamed: N2.LHDP, R20.2
unnamed: N2.RHDP, R21.1
unnamed: N3.A, R15.2
unnamed: N3.LHDP, R22.2
unnamed: N3.RHDP, R23.1
unnamed: N4.A, R16.2
unnamed: N4.LHDP, R24.2
unnamed: N4.RHDP, R25.1
unnamed: Q1.4 (G), R5.2
unnamed: Q1.1 (S), R6.1, R7.2
unnamed: R8.1, R12.2
unnamed: R5.1, U1.7 (GATE)
unnamed: R3.1, U1.4 (RT)
unnamed: C13.1, R7.1, U1.6 (SENSE)
unnamed: C12.1, U1.3 (SS)
unnamed: C10.1, R2.2, U1.1 (VC)
unnamed: R18.1, U3.4 (DRAIN0)
unnamed: N1.1, U3.5 (DRAIN1)
unnamed: N1.2, U3.6 (DRAIN2)
unnamed: N1.3, U3.7 (DRAIN3)
unnamed: N1.4, U3.14 (DRAIN4)
unnamed: N1.5, U3.15 (DRAIN5)
unnamed: N1.6, U3.16 (DRAIN6)
unnamed: N1.7, U3.17 (DRAIN7)
unnamed: U3.18 (SER_OUT), U4.3 (SER_IN)
unnamed: N1.8, U4.4 (DRAIN0)
unnamed: N1.9, U4.5 (DRAIN1)
unnamed: N1.0, U4.6 (DRAIN2)
unnamed: R19.2, U4.7 (DRAIN3)
unnamed: R20.1, U4.14 (DRAIN4)
unnamed: N2.1, U4.15 (DRAIN5)
unnamed: N2.2, U4.16 (DRAIN6)
unnamed: N2.3, U4.17 (DRAIN7)
unnamed: U4.18 (SER_OUT), U5.3 (SER_IN)
unnamed: N2.4, U5.4 (DRAIN0)
unnamed: N2.5, U5.5 (DRAIN1)
unnamed: N2.6, U5.6 (DRAIN2)
unnamed: N2.7, U5.7 (DRAIN3)
unnamed: N2.8, U5.14 (DRAIN4)
unnamed: N2.9, U5.15 (DRAIN5)
unnamed: N2.0, U5.16 (DRAIN6)
unnamed: R21.2, U5.17 (DRAIN7)
unnamed: U5.18 (SER_OUT), U6.3 (SER_IN)
unnamed: R22.1, U6.4 (DRAIN0)
unnamed: N3.1, U6.5 (DRAIN1)
unnamed: N3.2, U6.6 (DRAIN2)
unnamed: N3.3, U6.7 (DRAIN3)
unnamed: N3.4, U6.14 (DRAIN4)
unnamed: N3.5, U6.15 (DRAIN5)
unnamed: N3.6, U6.16 (DRAIN6)
unnamed: N3.7, U6.17 (DRAIN7)
unnamed: U6.18 (SER_OUT), U7.3 (SER_IN)
unnamed: N3.8, U7.4 (DRAIN0)
unnamed: N3.9, U7.5 (DRAIN1)
unnamed: N3.0, U7.6 (DRAIN2)
unnamed: R23.2, U7.7 (DRAIN3)
unnamed: R24.1, U7.14 (DRAIN4)
unnamed: N4.1, U7.15 (DRAIN5)
unnamed: N4.2, U7.16 (DRAIN6)
unnamed: N4.3, U7.17 (DRAIN7)
unnamed: U7.18 (SER_OUT), U8.3 (SER_IN)
unnamed: N4.4, U8.4 (DRAIN0)
unnamed: N4.5, U8.5 (DRAIN1)
unnamed: N4.6, U8.6 (DRAIN2)
unnamed: N4.7, U8.7 (DRAIN3)
unnamed: N4.8, U8.14 (DRAIN4)
unnamed: N4.9, U8.15 (DRAIN5)
unnamed: N4.0, U8.16 (DRAIN6)
unnamed: R25.2, U8.17 (DRAIN7)
OUT: J4.1 (OUT), U2.7 (GPIO0)
PSU_EN: U1.9 (~SHDN/UVLO), U2.11 (GPIO11)
RCLK: J7.5, U9.13
RX: J4.3 (RX), U2.5 (GPIO6)
SER_IN: J7.4, U9.1
SRCLK: J7.3, U9.3
TX: J4.2 (TX), U2.6 (GPIO7)
~ENABLE: U3.9 (~G), U4.9 (~G), U5.9 (~G), U6.9 (~G), U7.9 (~G), U8.9 (~G), U9.6
~RCLK: U3.12 (RCLK), U4.12 (RCLK), U5.12 (RCLK), U6.12 (RCLK), U7.12 (RCLK), U8.12 (RCLK), U9.12
~SER_IN: U3.3 (SER_IN), U9.2
~SRCLK: U3.13 (SRCK), U4.13 (SRCK), U5.13 (SRCK), U6.13 (SRCK), U7.13 (SRCK), U8.13 (SRCK), U9.4

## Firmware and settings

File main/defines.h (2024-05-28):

#if CONFIG_ESP32_C6_WROOM_1
    #define GPIO_PRESENCE_SENSOR GPIO_NUM_0
    #define GPIO_VBUS_CC2        GPIO_NUM_1
    #define GPIO_VBUS_CC1        GPIO_NUM_2
    #define GPIO_UART_RX         GPIO_NUM_6
    #define GPIO_UART_TX         GPIO_NUM_7
    #define GPIO_PSU_EN          GPIO_NUM_11
    #define GPIO_RCLK            GPIO_NUM_18
    #define GPIO_SRDATA          GPIO_NUM_19
    #define GPIO_SRCLK           GPIO_NUM_20
    #define GPIO_OUTPUT_EN       GPIO_NUM_21
#elif CONFIG_ESP32_C6_MINI_1
    #define GPIO_PRESENCE_SENSOR GPIO_NUM_0
    //#define GPIO_VBUS_CC2        GPIO_NUM_
    //#define GPIO_VBUS_CC1        GPIO_NUM_
    #define GPIO_UART_RX         GPIO_NUM_4
    #define GPIO_UART_TX         GPIO_NUM_5
    #define GPIO_PSU_EN          GPIO_NUM_7
    #define GPIO_RCLK            GPIO_NUM_15
    #define GPIO_SRDATA          GPIO_NUM_18
    #define GPIO_SRCLK           GPIO_NUM_19
    #define GPIO_OUTPUT_EN       GPIO_NUM_20
#endif

#define RMT_RESOLUTION_HZ 1000000 // 1MHZ, 1 tick = 1us

#define PWM_RESOLUTION_BITS 10    // PWM duty-cycle resolution is 0-1024

#define ENABLE  1
#define DISABLE 0

#define ESP_INTR_FLAG_DEFAULT 0

#define WIFI_CONNECTED_BIT BIT0
#define WIFI_FAIL_BIT      BIT1

#define TIMER_UPDATE_DISP 1
#define TIMER_ROLL_DISP   2
#define TIMER_NO_MOVEMENT 3

#define WIFI_SUCCESS 1
#define WIFI_FAILURE 2

#define MAIN_TASK_SETUP_DONE 1
#define ANIMATION_TASK_DONE  2

#define ESP_WIFI_SSID           CONFIG_ESP_WIFI_SSID
#define ESP_WIFI_PASS           CONFIG_ESP_WIFI_PASSWORD
#define ESP_MAXIMUM_RETRY       CONFIG_ESP_MAXIMUM_RETRY

#define SNTP_TIME_SERVER        CONFIG_SNTP_TIME_SERVER

#if CONFIG_ESP_WIFI_AUTH_OPEN
#define ESP_WIFI_SCAN_AUTH_MODE_THRESHOLD WIFI_AUTH_OPEN
#elif CONFIG_ESP_WIFI_AUTH_WEP
#define ESP_WIFI_SCAN_AUTH_MODE_THRESHOLD WIFI_AUTH_WEP
#elif CONFIG_ESP_WIFI_AUTH_WPA_PSK
#define ESP_WIFI_SCAN_AUTH_MODE_THRESHOLD WIFI_AUTH_WPA_PSK
#elif CONFIG_ESP_WIFI_AUTH_WPA2_PSK
#define ESP_WIFI_SCAN_AUTH_MODE_THRESHOLD WIFI_AUTH_WPA2_PSK
#elif CONFIG_ESP_WIFI_AUTH_WPA_WPA2_PSK
#define ESP_WIFI_SCAN_AUTH_MODE_THRESHOLD WIFI_AUTH_WPA_WPA2_PSK
#elif CONFIG_ESP_WIFI_AUTH_WPA3_PSK
#define ESP_WIFI_SCAN_AUTH_MODE_THRESHOLD WIFI_AUTH_WPA3_PSK
#elif CONFIG_ESP_WIFI_AUTH_WPA2_WPA3_PSK
#define ESP_WIFI_SCAN_AUTH_MODE_THRESHOLD WIFI_AUTH_WPA2_WPA3_PSK
#elif CONFIG_ESP_WIFI_AUTH_WAPI_PSK
#define ESP_WIFI_SCAN_AUTH_MODE_THRESHOLD WIFI_AUTH_WAPI_PSK
#endif

#if CONFIG_ESP_WPA3_SAE_PWE_HUNT_AND_PECK
#define ESP_WIFI_SAE_MODE WPA3_SAE_PWE_HUNT_AND_PECK
#define H2E_IDENTIFIER ""
#elif CONFIG_ESP_WPA3_SAE_PWE_HASH_TO_ELEMENT
#define ESP_WIFI_SAE_MODE WPA3_SAE_PWE_HASH_TO_ELEMENT
#define H2E_IDENTIFIER CONFIG_ESP_WIFI_PW_ID
#elif CONFIG_ESP_WPA3_SAE_PWE_BOTH
#define ESP_WIFI_SAE_MODE WPA3_SAE_PWE_BOTH
#define H2E_IDENTIFIER CONFIG_ESP_WIFI_PW_ID
#endif

#if CONFIG_BUILD_MAIN_PROGRAM
#define BUILD_MAIN_PROGRAM
#endif

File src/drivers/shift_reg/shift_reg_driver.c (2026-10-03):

#include <string.h>

#include "freertos/FreeRTOS.h"
#include "freertos/semphr.h"
#include "driver/gpio.h"
#include "driver/rmt_tx.h"
#include "esp_log.h"
#include "esp_rom_sys.h"

#include "defines.h"
#include "shift_reg_driver.h"

static const char *TAG = "ShiftReg";

static uint8_t CLK_DATA[6];
static uint8_t serial_data[6];
static SemaphoreHandle_t write_mutex;

static rmt_channel_handle_t SHIFT_REG_DATA_channel = NULL;
static rmt_tx_channel_config_t SHIFT_REG_DATA_channel_config = {
    .clk_src = RMT_CLK_SRC_DEFAULT,
    .gpio_num = GPIO_SHIFT_REG_DATA,
    .mem_block_symbols = 48,
    .resolution_hz = RMT_RESOLUTION_HZ,
    .trans_queue_depth = 1,
    .flags.invert_out = true,
    .flags.with_dma = false,
};

static rmt_channel_handle_t SHIFT_REG_CLOCK_channel = NULL;
static rmt_tx_channel_config_t SHIFT_REG_CLOCK_channel_config = {
    .clk_src = RMT_CLK_SRC_DEFAULT,
    .gpio_num = GPIO_SHIFT_REG_CLOCK,
    .mem_block_symbols = 48,
    .resolution_hz = RMT_RESOLUTION_HZ,
    .trans_queue_depth = 1,
    .flags.invert_out = true,
    .flags.with_dma = false,
};

static rmt_encoder_handle_t SHIFT_REG_DATA_encoder = NULL;
static rmt_bytes_encoder_config_t SHIFT_REG_DATA_encoder_config = {
    .bit0 = {
        .level0 = 0,
        .duration0 = 2,
        .level1 = 0,
        .duration1 = 2,
    },
    .bit1 = {
        .level0 = 1,
        .duration0 = 2,
        .level1 = 1,
        .duration1 = 2,
    },
    .flags.msb_first = 0,
};

static rmt_encoder_handle_t SHIFT_REG_CLOCK_encoder = NULL;
static rmt_bytes_encoder_config_t SHIFT_REG_CLOCK_encoder_config = {
    .bit0 = {
        .level0 = 0,
        .duration0 = 1,
        .level1 = 0,
        .duration1 = 1,
    },
    .bit1 = {
        .level0 = 0,
        .duration0 = 2,
        .level1 = 1,
        .duration1 = 2,
    },
    .flags.msb_first = 0,
};

static rmt_transmit_config_t SHIFT_REG_DATA_transmit_config = {
    .loop_count = 0,
    .flags.eot_level = 0,
};

static rmt_transmit_config_t SHIFT_REG_CLOCK_transmit_config = {
    .loop_count = 0,
    .flags.eot_level = 0,
};

static rmt_sync_manager_handle_t synchro = NULL;

static void shift_reg_transmit(uint64_t data)
{
    for (int i = 0; i < 6; i++) {
        serial_data[i] = (uint8_t)(data >> (i * 8));
    }

    ESP_ERROR_CHECK(rmt_sync_reset(synchro));
    ESP_ERROR_CHECK(rmt_transmit(SHIFT_REG_CLOCK_channel, SHIFT_REG_CLOCK_encoder, CLK_DATA, sizeof(CLK_DATA),
                                 &SHIFT_REG_CLOCK_transmit_config));
    ESP_ERROR_CHECK(rmt_transmit(SHIFT_REG_DATA_channel, SHIFT_REG_DATA_encoder, serial_data, sizeof(serial_data),
                                 &SHIFT_REG_DATA_transmit_config));

    ESP_ERROR_CHECK(rmt_tx_wait_all_done(SHIFT_REG_DATA_channel, portMAX_DELAY));
    ESP_ERROR_CHECK(rmt_tx_wait_all_done(SHIFT_REG_CLOCK_channel, portMAX_DELAY));

    gpio_set_level(GPIO_SHIFT_REG_LATCH, 0);
    esp_rom_delay_us(10);
    gpio_set_level(GPIO_SHIFT_REG_LATCH, 1);
}

void shift_reg_driver_init(void)
{
    memset(CLK_DATA, 0xFF, sizeof(CLK_DATA));
    write_mutex = xSemaphoreCreateMutex();
    configASSERT(write_mutex);

    gpio_config_t io_conf = {
        .pin_bit_mask = (1ULL << GPIO_SHIFT_REG_LATCH),
        .intr_type = GPIO_INTR_DISABLE,
        .mode = GPIO_MODE_OUTPUT,
        .pull_up_en = GPIO_PULLUP_DISABLE,
        .pull_down_en = GPIO_PULLDOWN_DISABLE,
    };
    gpio_config(&io_conf);
    gpio_set_level(GPIO_SHIFT_REG_LATCH, 0);

    ESP_ERROR_CHECK(rmt_new_tx_channel(&SHIFT_REG_DATA_channel_config, &SHIFT_REG_DATA_channel));
    ESP_ERROR_CHECK(rmt_new_tx_channel(&SHIFT_REG_CLOCK_channel_config, &SHIFT_REG_CLOCK_channel));
    ESP_ERROR_CHECK(rmt_new_bytes_encoder(&SHIFT_REG_DATA_encoder_config, &SHIFT_REG_DATA_encoder));
    ESP_ERROR_CHECK(rmt_new_bytes_encoder(&SHIFT_REG_CLOCK_encoder_config, &SHIFT_REG_CLOCK_encoder));
    ESP_ERROR_CHECK(rmt_enable(SHIFT_REG_DATA_channel));
    ESP_ERROR_CHECK(rmt_enable(SHIFT_REG_CLOCK_channel));

    rmt_channel_handle_t channels[2] = {SHIFT_REG_DATA_channel, SHIFT_REG_CLOCK_channel};
    rmt_sync_manager_config_t synchro_config = {
        .tx_channel_array = channels,
        .array_size = sizeof(channels) / sizeof(channels[0]),
    };
    ESP_ERROR_CHECK(rmt_new_sync_manager(&synchro_config, &synchro));

    shift_reg_transmit(0);

    ESP_LOGI(TAG, "Shift register driver initialized (RMT + latch on GPIO%d)", GPIO_SHIFT_REG_LATCH);
}

void shift_reg_driver_write(uint64_t data)
{
    xSemaphoreTake(write_mutex, portMAX_DELAY);
    shift_reg_transmit(data);
    xSemaphoreGive(write_mutex);
}

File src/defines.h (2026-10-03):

#pragma once

#include "driver/gpio.h"

#if CONFIG_ESP32_C6_WROOM_1
    #define GPIO_PRESENCE_SENSOR GPIO_NUM_0
    #define GPIO_PSU_EN          GPIO_NUM_11
    #define GPIO_SHIFT_REG_LATCH          GPIO_NUM_18
    #define GPIO_SHIFT_REG_DATA           GPIO_NUM_19
    #define GPIO_SHIFT_REG_CLOCK          GPIO_NUM_20
    #define GPIO_SHIFT_REG_OUTPUT_ENABLE  GPIO_NUM_21
#elif CONFIG_ESP32_C6_MINI_1
    #define GPIO_PRESENCE_SENSOR GPIO_NUM_0
    #define GPIO_PSU_EN          GPIO_NUM_7
    #define GPIO_SHIFT_REG_LATCH          GPIO_NUM_15
    #define GPIO_SHIFT_REG_DATA           GPIO_NUM_18
    #define GPIO_SHIFT_REG_CLOCK          GPIO_NUM_19
    #define GPIO_SHIFT_REG_OUTPUT_ENABLE  GPIO_NUM_20
#else
    #define GPIO_PRESENCE_SENSOR GPIO_NUM_0
    #define GPIO_PSU_EN          GPIO_NUM_11
    #define GPIO_SHIFT_REG_LATCH          GPIO_NUM_18
    #define GPIO_SHIFT_REG_DATA           GPIO_NUM_19
    #define GPIO_SHIFT_REG_CLOCK          GPIO_NUM_20
    #define GPIO_SHIFT_REG_OUTPUT_ENABLE  GPIO_NUM_21
#endif

#define RMT_RESOLUTION_HZ 1000000
#define PWM_RESOLUTION_BITS 10

#define TIMER_TICK        1
#define TIMER_ROLL_DISP   2
#define TIMER_NO_MOVEMENT 3

#define ESP_MAXIMUM_RETRY CONFIG_ESP_MAXIMUM_RETRY
#define SNTP_TIME_SERVER CONFIG_SNTP_TIME_SERVER
#define SNTP_TIME_SERVER_BACKUP CONFIG_SNTP_TIME_SERVER_BACKUP

#define PRESENCE_DEBOUNCE_MS 50

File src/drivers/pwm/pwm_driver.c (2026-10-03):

#include "driver/ledc.h"
#include "esp_log.h"

#include "defines.h"
#include "pwm_driver.h"

static const char *TAG = "PWM";

#define PWM_FREQ_HZ 30000

void pwm_driver_init(int gpio_num)
{
    ledc_timer_config_t pwm_timer = {
        .duty_resolution = PWM_RESOLUTION_BITS,
        .freq_hz         = PWM_FREQ_HZ,
        .speed_mode      = LEDC_LOW_SPEED_MODE,
        .timer_num       = LEDC_TIMER_0,
        .clk_cfg         = LEDC_AUTO_CLK,
    };
    ESP_ERROR_CHECK(ledc_timer_config(&pwm_timer));

    ledc_channel_config_t pwm_channel_config = {
        .gpio_num   = gpio_num,
        .speed_mode = LEDC_LOW_SPEED_MODE,
        .channel    = LEDC_CHANNEL_0,
        .intr_type  = LEDC_INTR_DISABLE,
        .timer_sel  = LEDC_TIMER_0,
        .duty       = 0,
        .hpoint     = 0,
        .flags.output_invert = 0,
    };
    ESP_ERROR_CHECK(ledc_channel_config(&pwm_channel_config));
    ESP_ERROR_CHECK(ledc_fade_func_install(0));

    ESP_LOGI(TAG, "PWM initialized on GPIO %d (%d Hz, %d-bit)",
             gpio_num, PWM_FREQ_HZ, PWM_RESOLUTION_BITS);
}

void pwm_driver_set_duty(uint32_t duty_cycle_percent)
{
    if (duty_cycle_percent > 100) {
        duty_cycle_percent = 100;
    }

    const uint32_t max_duty = (1u << PWM_RESOLUTION_BITS) - 1u;
    const uint32_t duty = (max_duty * duty_cycle_percent) / 100u;

    ESP_ERROR_CHECK(ledc_set_duty_and_update(LEDC_LOW_SPEED_MODE, LEDC_CHANNEL_0, duty, 0));
}

void pwm_driver_set_duty_counts(uint32_t duty)
{
    const uint32_t max_duty = (1u << PWM_RESOLUTION_BITS) - 1u;
    if (duty > max_duty) {
        duty = max_duty;
    }
    ESP_ERROR_CHECK(ledc_set_duty_and_update(LEDC_LOW_SPEED_MODE, LEDC_CHANNEL_0, duty, 0));
}

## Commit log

2026-09-27 Split firmware into drivers and restore a proper IDF main component.
    Move clock, display, GPIO, PSU, PWM, shift-register, Wi-Fi, and web server
    into src/ modules so timers, occupancy, and networking stay out of busy-wait
    and ISR-unsafe paths. Stop tracking sdkconfig in favor of defaults.
2026-10-03 Add a web configuration page so display, time, brightness, and Wi-Fi can be changed on the clock and kept after reboot.
    [defines.h, display.c, presence_driver.c]
2026-10-03 Fix sub-tick display timing
    Raise the FreeRTOS tick rate to 1000 Hz and use absolute microsecond deadlines so millisecond display waits do not collapse into busy loops. Replace the stepped crossfade with 1 kHz pulse-density modulation, skip redundant shift-register writes, and set the default fade duration to 500 ms.
    Verified with an ESP-IDF build, UART flash, and successful device startup with Wi-Fi and SNTP.
    [display.c]
2026-10-03 Report settings persistence failures
    Propagate NVS open, write, and commit errors through the clock and display settings APIs. Make configuration responses and tube feedback report failure when settings cannot be persisted, and prevent test actions from running after an unsuccessful save.
    [display.c]
2026-10-03 Synchronize brightness and PSU state
    Protect ramp, transition-test, presence, brightness, and high-voltage state with a dedicated recursive mutex. Keep persistence operations outside the critical section so flash writes do not block the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
2026-10-03 Bound HTTP form receive retries
    Use a shared form-body receiver for Wi-Fi and configuration POST requests. Stop after three socket timeouts and return specific responses for oversized, timed-out, and incomplete request bodies inste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
2026-10-03 Batch web settings persistence
    Apply brightness, presence, and display form values through grouped settings APIs. Recalculate brightness once and reduce persistence to one NVS commit per affected namespace while preserving disabled-field values and existing save error reporting.
    [display.c]
2026-10-03 Remove unused public APIs and board macros
    Drop clock, display, and Wi-Fi helpers that have no callers, including custom timezone and force-on paths. Stop persisting the unused force-on key and record the UART and USB-C CC pins in the hardware document now that they are no longer firmware macros.
    [defines.h, display.c]
2026-10-03 Fix extra spaces in brightness ramp clamp
    Remove the stray spaces in the upper-bound check of start_ramp so the else if matches the surrounding clock.c formatting. The clamp behavior is unchanged.
2026-10-03 Remove unused compile-time Wi-Fi configuration
    Drop the unused SSID, password, and authentication Kconfig symbols and the obsolete main/test program defaults. Document the NVS setup flow, including Join and Forget current network, and keep menuco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
2026-10-03 Add Cursor rules and VS Code flash settings
    Track the always-on Cursor rules for commit messages and flashing firmware after source changes. Track the VS Code serial port and UART flash type used to program the clock.
2026-10-03 Add KiCad models of the clock boards
    Include the lower supply board, the upper tube board, and the panel, with the custom symbols, footprints, and 3D models those boards reference. Leave KiCad backups, footprint caches, and manufacturin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
    [530480510.stp, NX-SZP-IN14-v01.STEP, Sulari.kicad_pcb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]
2026-10-03 Document the clock and set night mode off by default
    Rewrite the README as a user guide covering setup, display modes, and how the tubes, shift registers, flyback supply, and presence sensor work. Add configuration screenshots, display-mode GIFs, and b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
2026-10-03 Add the flyback LTspice model
    The 170 V flyback supply is stored under HW/ltspice as two schematics:
    one with a coupled-inductor model and the BSC059N04LS6, and one using
    the Würth 750032051 transformer symbol. The Würth WE-FB library and
    Infineon OptiMOS models are included with the schematics. Simulation
    waveform dumps were left out.
2026-10-03 Add the BOM and Gerber fabrication files
    Include the spreadsheet BOM and the KiCad Gerber outputs for the mouse-bite
    panel and for the top and bottom boards. Drill files and the Gerber job
    files are included with each set, together with the pick-and-place
    coordinates and the placement drawing.
    [BOM.xlsx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]

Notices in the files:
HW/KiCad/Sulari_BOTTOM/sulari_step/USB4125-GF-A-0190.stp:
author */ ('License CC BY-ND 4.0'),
